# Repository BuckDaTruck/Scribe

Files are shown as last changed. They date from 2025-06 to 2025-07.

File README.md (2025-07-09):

# Scribe Audio Logger

Scribe transforms a Raspberry Pi Zero 2 W into a compact field recorder. Audio is captured continuously and each press of a hardware button marks highlights. Files can be queued for upload to a web server so recordings remain safe even if the Pi is lost.

This repository is organised into two main parts:

- **Device/** – firmware, wiring guides and setup instructions for the Raspberry Pi.
- **WebServer/** – a minimal PHP endpoint and helper scripts to receive uploads.

---

## Features

- Continuous audio capture split into timestamped chunks
- Highlight logging via a physical button
- Manual or automated upload of recordings to a server
- RGB LED status feedback and simple push‑button controls
- Old files are pruned after a successful upload to free space

---

## Hardware Overview

The hardware build uses the following components:

- Raspberry Pi Zero 2 W
- INMP441 I²S microphone
- Two push buttons: one for highlights and one for initiating uploads
- RGB LED with resistors for visual feedback

Wiring diagrams are provided in
[Device/wiring_instructions.md](Device/wiring_instructions.md).
See [Device/parts_list.md](Device/parts_list.md) for a complete list of
required components.

## 3D-Printed Case

All enclosure files live in the `Device/Cad/` directory. The STL models were
printed on an **Anycubic S1** and should be compatible with most desktop
printers. If you want to modify the design, the original Onshape project
is available at [this link](https://cad.onshape.com/documents/3eb0c03f667fd218b6465f3e/w/64f544e1ef4dcc4bc9220305/e/b0f011cba6411f833e96eb2d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).
A preconfigured `Scribe.3mf` file is also included for quick slicing.

---

## Quick Start

1. Assemble the hardware as described in the wiring instructions.
2. Follow the steps in
   [Device/Firmware/setup_instructions.md](Device/Firmware/setup_instructions.md)
   to flash the operating system and install dependencies.
3. Boot the Pi—recording starts automatically.
4. Press the highlight button to log an interesting moment.
5. Press the upload button or wait for automatic uploads to send files to the
   server configured in `recorder.py`.

Recordings are stored as `.opus` files and highlight timestamps are saved to
CSV. Successful uploads remove the local copies to keep the SD card clean.

---

## Web Server

The `WebServer` directory contains `upload.php`, a small PHP script that accepts
incoming audio and CSV files. Set `$apiKey` and `$uploadBaseDir` inside the
script to match your environment. A Python utility, `test.py`, demonstrates how
to POST files to the server for testing without the device.

---

## Repository Layout

```
Device/Cad/     # 3D models and CAD files for the case
Device/         # Firmware, setup scripts and hardware docs
WebServer/      # PHP endpoint and test client
README.md       # Project overview (this file)
```

---

## Contributing

Bug reports and pull requests are welcome. Feel free to open an issue if you run
into problems while building your own logger.

---

## License

This project is released under the MIT license. See individual source files for
full license text.

---

## Credits

Created and maintained by Buckley Wiley.

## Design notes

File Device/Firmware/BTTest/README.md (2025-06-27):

# Bluetooth Pairing Utility

This folder contains a small script to pair your Raspberry Pi with a mobile phone and use the phone's internet connection via Bluetooth PAN. A single button triggers pairing or connecting depending on whether a paired device is already saved.

## Prerequisites

Install the required packages once:

```bash
sudo apt update
sudo apt install -y bluetooth bluez pi-bluetooth rfkill python3-gpiozero python3-requests
```

(Optional) Change the advertised Bluetooth name by editing `/etc/bluetooth/main.conf` and setting:

```ini
Name = Buckley-Scribe
```

Restart Bluetooth to apply the change:

```bash
sudo systemctl restart bluetooth
```

## Usage

1. Run the helper script to clone the repository and start the pairing utility:

```bash
bash start_BT.sh
```

   This installs dependencies, pulls the repository and launches `btpair.py`.
2. Once running, press the connected button to initiate pairing. If the Pi already knows a device, it attempts to reconnect via PAN instead.
3. The script gives feedback through the RGB LED:
   - **Yellow** – pairing mode active
   - **Blue pulse** – waiting for user action
   - **Green** – internet connection detected
   - **Red** – connection failed

The MAC address of the paired phone is stored at `/etc/scribe/phone_mac.conf` for future connections.

## Files

- `btpair.py` – main script handling pairing, connection and LED feedback
- `start_BT.sh` – helper script that clones this repository and runs `btpair.py`
- `instructions.md` – brief setup notes

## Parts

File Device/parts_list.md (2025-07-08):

# Raspberry Pi Audio Logger Parts List

This list covers all hardware needed to assemble the logger.

## Electronics

- **Raspberry Pi Zero 2 W**  
  https://www.amazon.com/Pi-Zero-WH-Quad-Core-Bluetooth/dp/B0DKKXS4RV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
- **INMP441 Microphone (I2S)**  
  https://www.amazon.com/dp/B09G4RNT3G?ref_=ppx_hzsearch_conn_dt_b_fed_asin_title_3
- **RGB LED (Common Cathode)**  
  https://www.amazon.com/Tricolor-Multicolor-Lighting-Electronics-Components/dp/B01C19ENDM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
- **2x Push Buttons**  
  https://www.amazon.com/TWTADE-Yellow-Orange-6x6x5mm-Tactile/dp/B07C7211PJ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
- **3x 330Ω Resistors** (RGB LED)
- **2x 10kΩ Resistors** (buttons)
  https://www.amazon.com/TMH-525-Metal-Film-Resistor/dp/B0FD3LP495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
- **Perma-Proto Board**  
  https://www.amazon.com/dp/B0B2RQDJ54?ref=ppx_yo2ov_dt_b_fed_asin_title
- **M2.5 Standoffs**  
  https://www.amazon.com/dp/B0756CW6Y2?ref=ppx_yo2ov_dt_b_fed_asin_title
- **5V Buck Converter**  
  https://www.amazon.com/dp/B07L76KLRY?ref=ppx_yo2ov_dt_b_fed_asin_title
- **1100mAh Battery**  
  https://www.amazon.com/Hiteuoms-Rechargeable-Development-Protection-Insulated/dp/B0F3875HJY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
- **USB-C Lithium Battery Charger**  
  https://www.amazon.com/Lithium-Battery-Charging-Protection-Functions/dp/B07MDPLQ18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

## 3D Printed Parts

The `Device/Cad` directory contains STL models for printing:

- **Scribe - Back Shell.stl**
- **Scribe - TopFrame.stl**
- **2x Scribe - Button Extender.stl** (one for each button)
- **Lanyard or strap** for carrying the recorder

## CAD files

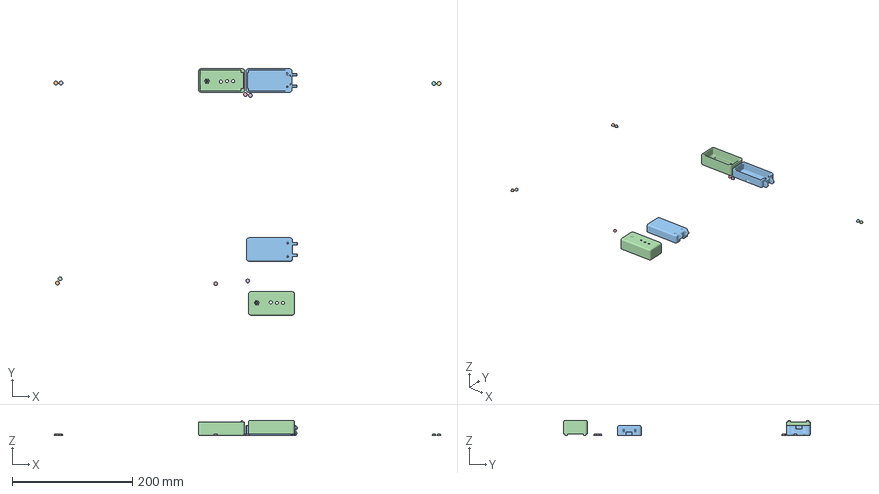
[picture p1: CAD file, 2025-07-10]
Device/Cad/Scribe.3mf
643.0 x 409.7 x 25.7 mm
Scribe - Button Extender.stl x 10
Scribe - Back Shell.stl x 2
Scribe - TopFrame.stl x 2

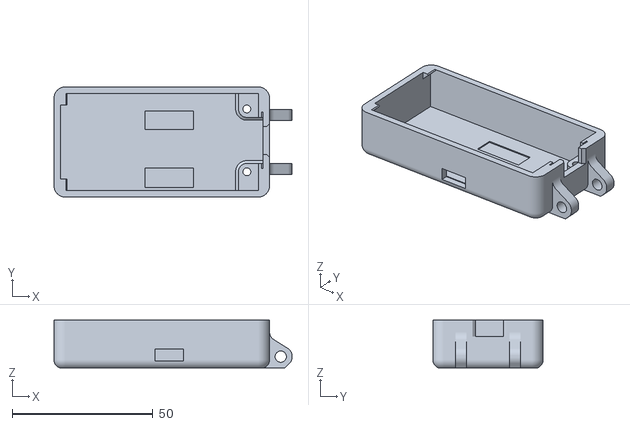
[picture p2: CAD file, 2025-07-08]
Device/Cad/Scribe - Back Shell.stl
84.7 x 39.2 x 17.0

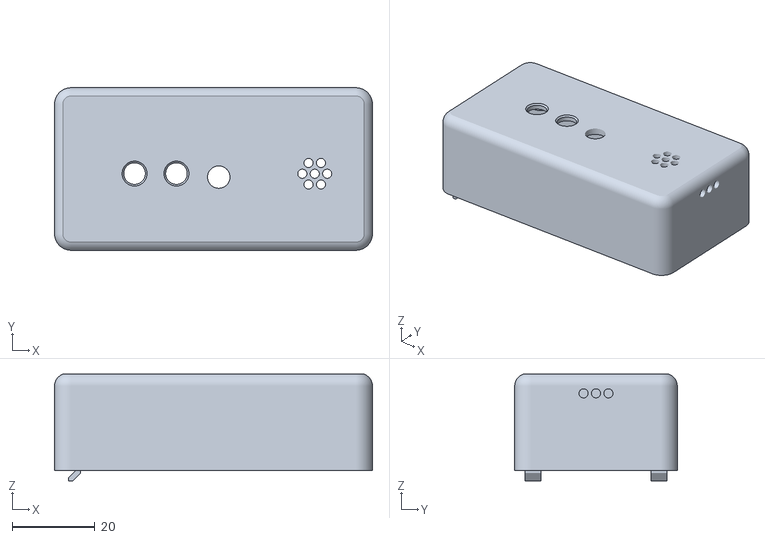
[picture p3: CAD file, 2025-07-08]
Device/Cad/Scribe - TopFrame.stl
76.7 x 39.2 x 25.7

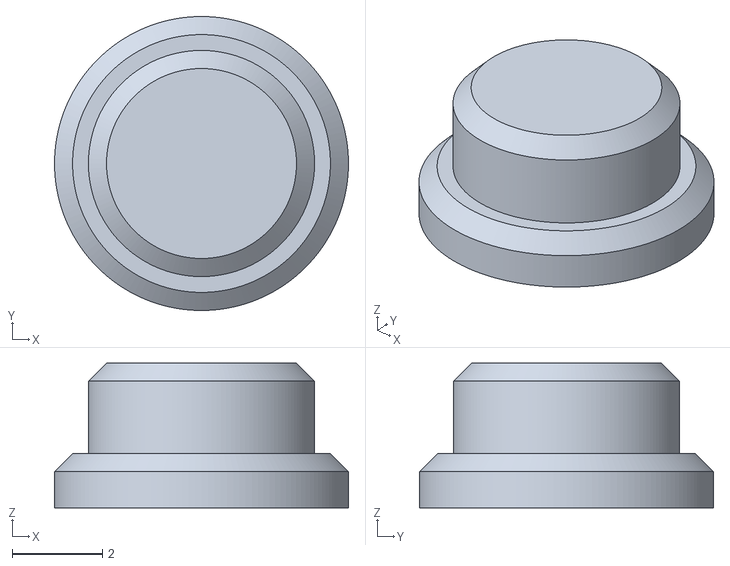
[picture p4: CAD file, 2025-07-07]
Device/Cad/Scribe - Button Extender.stl
6.50 x 6.50 x 3.20

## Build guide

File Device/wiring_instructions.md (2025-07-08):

# Raspberry Pi Audio Logger Wiring Instructions

This guide explains how to connect the electronics on the breadboard. A full list of parts is available in [parts_list.md](parts_list.md).

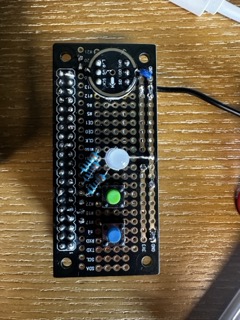
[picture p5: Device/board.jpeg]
Breadboard layout


## Wiring Diagram

### INMP441 Microphone (I2S)

| INMP441 Pin | Raspberry Pi Pin | Function |
| --- | --- | --- |
| VCC | Pin 1 (3.3V) | Power |
| GND | Pin 6 (GND) | Ground |
| WS (L/R) | Pin 35 (GPIO19)  | Word Select |
| SCK | Pin 12 (GPIO18)  | Bit Clock |
| SD | Pin 38 (GPIO20)  | Data |

> Note: You may need to enable I2S in `/boot/config.txt`:
>
> ```
> dtparam=i2s=on
> ```

---

### RGB LED (Common Cathode)

| LED Pin | Resistor | Raspberry Pi Pin | GPIO | Color  |
| --- | --- | --- | --- | --- |
| R | 330Ω | Pin 18 | GPIO24 | Red |
| G | 330Ω | Pin 16 | GPIO23 | Green  |
| B | 330Ω | Pin 15 | GPIO22 | Blue |
| Cathode | None | Pin 14 (GND) | GND | Ground |

---

### Buttons

| Button | Raspberry Pi Pin | GPIO | Function |
| --- | --- | --- | --- |
| 1 | Pin 11 | GPIO17 | Upload trigger |
| 2 | Pin 13 | GPIO27 | Highlight trigger |

Use internal pull-up resistors; buttons should connect GPIO to **GND** when pressed.

---

## Power

- You can power the Pi using a 5V lithium battery (e.g., 18650 with regulator) connected to:
  - **Pin 2 or 4** (5V)
  - **Pin 6** (GND)

Alternatively, power via USB as usual.

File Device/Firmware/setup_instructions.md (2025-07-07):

# Raspberry Pi Audio Logger Setup Instructions

## Step 1: Download Minimal OS

Download Raspberry Pi OS Lite (64-bit) from the [official Raspberry Pi website](https://www.raspberrypi.com/software/operating-systems/#raspberry-pi-os-64-bit) and flash it to a micro‑SD card using Raspberry Pi Imager or a similar tool.

---

## Step 2: Configure Boot Settings

After flashing the card, mount the **boot** partition and add the following files so that the Pi connects to your network and allows SSH on first boot:

### Enable SSH

Create an empty file named `ssh`:

```bash
touch ssh
```

### Wi‑Fi Configuration

Create a file named `wpa_supplicant.conf` with your network details:

```bash
country=US
ctrl_interface=DIR=/var/run/wpa_supplicant GROUP=netdev
network={
    ssid="YourWiFi"
    psk="YourPassword"
    key_mgmt=WPA-PSK
}
```

---

## Step 3: Install Scribe Firmware

1. Boot the Pi and log in via SSH.
2. Clone this repository:

```bash
git clone https://github.com/BuckDaTruck/Scribe.git
```

3. Move the startup script to your home directory (the main directory) so it can be used at boot:

```bash
cd Scribe/Device/Firmware
mv start_scribe.sh ~/start_scribe.sh
chmod +x ~/start_scribe.sh
```

4. Run the helper script to install dependencies and start the recorder:

```bash
bash ~/start_scribe.sh
```

`start_scribe.sh` installs required packages, uses `requirements.txt` to install Python dependencies, and launches `recorder.py`.

If you prefer a manual setup, run the following instead of the script:

```bash
sudo apt-get update
sudo apt-get install -y python3 python3-pip alsa-utils git
pip3 install -r requirements.txt
python3 recorder.py
```

---

## Step 4: Optional – Run on Boot

After moving `start_scribe.sh` to your home directory, you can configure
systemd to run it automatically on boot:

```bash
sudo nano /etc/systemd/system/scribe.service
```

Insert:

```ini
[Unit]
Description=Scribe Recorder
After=network.target

[Service]
ExecStart=/bin/bash /home/pi/start_scribe.sh
Restart=always
User=pi

[Install]
WantedBy=multi-user.target
```

Enable and start the service:

```bash
sudo systemctl daemon-reload
sudo systemctl enable scribe.service
sudo systemctl start scribe.service
```

To stop the service and disable it from starting at boot:

```bash
sudo systemctl stop scribe.service
sudo systemctl disable scribe.service
```

---

## Step 5: Record

After running `start_scribe.sh` or enabling the service, the Pi begins recording immediately. Use the connected buttons to mark highlights and to upload recordings as defined in `recorder.py`.

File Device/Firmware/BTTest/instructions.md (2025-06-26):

✅ STEP 1: Install Required Packages
Run this once:

bash
Copy
Edit
sudo apt update
sudo apt install -y bluetooth bluez pi-bluetooth rfkill python3-gpiozero python3-requests
✅ STEP 2: Change the Bluetooth Name Only
Edit the Bluetooth config:

bash
Copy
Edit
sudo nano /etc/bluetooth/main.conf
Find (or add) the following line under [General]:

ini
Copy
Edit
Name = Buckley-Scribe
Then restart Bluetooth:

bash
Copy
Edit
sudo systemctl restart bluetooth
✅ Your Pi will now appear as Buckley-Scribe when other devices scan via Bluetooth.

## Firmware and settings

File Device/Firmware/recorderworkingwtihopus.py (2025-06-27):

import os
import time
import uuid
import threading
import subprocess
import datetime
import glob
import requests
import math
import logging
from gpiozero import Button, PWMLED
#:~ $ ./start_scribe.sh 
# === CONFIG ===
DEVICE_ID = "Buckley-Scribe-v1.1"
SCRIPT_DIR = os.path.dirname(os.path.realpath(__file__))
AUDIO_DIR = SCRIPT_DIR
os.makedirs(AUDIO_DIR, exist_ok=True)

UPLOAD_URL = 'https://buckleywiley.com/Scribe/upload.php'
API_KEY = '@YourPassword123'
BUTTON_HIGHLIGHT = Button(27, bounce_time=0.1)
BUTTON_UPLOAD = Button(17, bounce_time=0.1)
CHUNK_DURATION = .5 * 60  # 30 minutes
MAX_UPLOADED = 5
last_upload_time = 0
UPLOAD_DEBOUNCE_SEC = 2.0  # Prevent triggering more than once every 2 seconds

# === LOGGING SETUP ===
LOG_PATH = os.path.join(SCRIPT_DIR, 'scribe.log')
logging.basicConfig(
    filename=LOG_PATH,
    filemode='a',
    format='[%(asctime)s] %(levelname)s: %(message)s',
    datefmt='%Y-%m-%d %H:%M:%S',
    level=logging.INFO
)

def log(message, level='info'):
    print(message)
    getattr(logging, level)(message)

# === LED SETUP ===
led_r = PWMLED(24)
led_g = PWMLED(23)
led_b = PWMLED(22)

def set_led(r=0, g=0, b=0):
    led_r.value = r
    led_g.value = g
    led_b.value = b

def pulse_led(r=0, g=0, b=0, duration=10, delay=0.05):
    stop_event = threading.Event()
    def pulser():
        start = time.time()
        while time.time() - start < duration and not stop_event.is_set():
            t = time.time() * 2
            brightness = (math.sin(t) + 1) / 2
            led_r.value = brightness * r
            led_g.value = brightness * g
            led_b.value = brightness * b
            time.sleep(delay)
        if not stop_event.is_set():
            set_led(0, 0, 0)
    thread = threading.Thread(target=pulser, daemon=True)
    thread.start()
    return stop_event

# === TRIPLE TAP DETECTION ===
last_tap_time = 0
tap_count = 0
idle_mode = False
pulse_thread = None
pulse_event = threading.Event()

def idle_led_pulse():
    while not pulse_event.is_set():
        for i in range(100):
            if pulse_event.is_set(): return
            val = (math.sin(time.time() * 2) + 1) / 2
            led_g.value = val
            led_b.value = 1 - val
            time.sleep(0.05)
        set_led(0, 0, 0)


def quick_flash(r=0, g=0, b=0, duration=0.2):
    set_led(r, g, b)
    time.sleep(duration)
    set_led(0, 0, 0)

def set_error_led():
    set_led(r=1, g=0, b=0)

def startup_sequence():
    log("[SYSTEM] Running startup LED sequence...")
    colors = [
        (1, 0, 0),   # Red
        (1, 0.5, 0), # Orange
        (1, 1, 0),   # Yellow
        (0, 1, 0),   # Green
        (0, 0, 1),   # Blue
        (0.29, 0, 0.51), # Indigo
        (0.56, 0, 1),    # Violet
    ]
    for r, g, b in colors:
        set_led(r, g, b)
        time.sleep(0.2)
    set_led(0, 0, 0)
    time.sleep(0.3)
    set_led(1, 1, 1)
    time.sleep(0.2)
    set_led(0, 0, 0)
    log("[SYSTEM] LED sequence complete.")

# === STATE ===
current_arecord_proc = None
current_lame_proc = None
highlight_lock = threading.Lock()
highlighting = []
highlight_led_stop = None
session_id = uuid.uuid4().hex[:8]
session_part = 1

# === AUDIO RECORDING ===
def start_new_recording():
    global current_arecord_proc, current_lame_proc, session_part, current_csv_path
    timestamp = datetime.datetime.now().strftime('%Y-%m-%d_%H-%M-%S')
    print(f"Session ID {session_id}")
    filename = f"part_{session_part:04}.opus"
    filepath = os.path.join(AUDIO_DIR, filename)
    current_csv_path = os.path.join(AUDIO_DIR, f"{session_id}_Highlights.csv")
    session_part += 1

    log(f"[INFO] Starting opus recording: {filename}")
    current_arecord_proc = subprocess.Popen([
        'arecord', '-D', 'plughw:1,0', '-f', 'S16_LE', '-r', '88200', '-c', '1',
        '-t', 'raw', '-q', '-',
    ], stdout=subprocess.PIPE)

    sox_proc = subprocess.Popen([
    'sox', '-t', 'raw', '-r', '16000', '-e', 'signed', '-b', '16', '-c', '1', '-',  # raw PCM input
    '-t', 'raw', '-', 'gain', '10'  # actual amplification
    ], stdin=current_arecord_proc.stdout, stdout=subprocess.PIPE)

    current_lame_proc = subprocess.Popen([
    'opusenc', '--raw', '--raw-rate', '88200', '--raw-chan', '1', '-', filepath
    ], stdin=sox_proc.stdout, stdout=subprocess.DEVNULL, stderr=subprocess.DEVNULL)

    sox_proc.stdout.close()
    current_arecord_proc.stdout.close()
    set_led(r=0, g=1, b=0)
    return filepath
#opus works Finally
# === HIGHLIGHT BUTTON ===
def on_highlight_pressed():
    global highlight_led_stop, current_csv_path
    press_time = datetime.datetime.now()
    start_time = press_time - datetime.timedelta(seconds=10)
    end_time = press_time + datetime.timedelta(seconds=10)

    log(f"[HIGHLIGHT] Start: {start_time}, End: {end_time}")
    with highlight_lock:
        highlighting.append((start_time, press_time, end_time))

    if current_csv_path:
        with open(current_csv_path, 'a') as f:
            f.write(f"{start_time},{press_time},{end_time}\n")

    if highlight_led_stop:
        highlight_led_stop.set()
        set_led(r=0, g=1, b=0)

    highlight_led_stop = pulse_led(r=0, g=1, b=0, duration=5 * 60)

# === UPLOAD BUTTON ===
def on_upload_pressed():
    global idle_mode, pulse_event, last_upload_time, session_id, session_part
    now = time.time()

    # Manual debounce protection
    if now - last_upload_time < UPLOAD_DEBOUNCE_SEC:
        log("[UPLOAD] Ignored: Debounced repeated press.")
        return
    last_upload_time = now

    if not idle_mode:
        log("[UPLOAD] Upload button pressed. Stopping and entering idle mode.")
        if current_arecord_proc:
            current_arecord_proc.terminate()
            current_arecord_proc.wait()
        if current_lame_proc:
            current_lame_proc.terminate()
            current_lame_proc.wait()
        prev_filename = f"part_{session_part - 1:04}.opus"
        upload(prev_filename)
        idle_mode = True
        pulse_event.clear()
        pulse_event = threading.Event()
        threading.Thread(target=idle_led_pulse, daemon=True).start()
    else:
        log("[UPLOAD] Upload button pressed. Starting new recording session.")
        pulse_event.set()  # stop pulsing
        set_led(0, 0, 0)
        idle_mode = False
        session_id = uuid.uuid4().hex[:8]
        session_part = 1
        start_new_recording()


BUTTON_HIGHLIGHT.when_pressed = on_highlight_pressed
BUTTON_UPLOAD.when_pressed = on_upload_pressed

# === FILE UPLOAD ===
def upload(target_opus_filename):
    global highlight_led_stop
    opus_path = os.path.join(AUDIO_DIR, target_opus_filename)

    if not os.path.isfile(opus_path):
        log(f"[UPLOAD] File not found: {opus_path}", level='error')
        return

    # Find the CSV file (current session)
    csv_files = glob.glob(os.path.join(AUDIO_DIR, "*.csv"))
    csv_path = csv_files[0] if csv_files else None

    multipart = {
        'api_key': API_KEY,
        'device_id': DEVICE_ID,
        'session_id': session_id
    }

    files = {}
    try:
        files[target_opus_filename] = open(opus_path, 'rb')
        if csv_path:
            files[os.path.basename(csv_path)] = open(csv_path, 'rb')

        log(f"[UPLOAD] Uploading: {list(files.keys())}")
        pulse = pulse_led(r=0, g=0, b=1, duration=999)

        response = requests.post(UPLOAD_URL, files=files, data=multipart)
        log(f"[UPLOAD] Response: {response.status_code} - {response.text}")

        if pulse:
            pulse.set()
        set_led(0, 0, 0)

        if response.status_code == 200:
            try:
                os.remove(opus_path)
                log(f"[UPLOAD] Deleted: {opus_path}")
            except Exception as e:
                log(f"[UPLOAD] Delete failed for {opus_path}: {e}", level='error')
            if csv_path:
                try:
                    os.remove(csv_path)
                    log(f"[UPLOAD] Deleted: {csv_path}")
                except Exception as e:
                    log(f"[UPLOAD] Delete failed for {csv_path}: {e}", level='error')
            quick_flash(b=1)
        else:
            log("[UPLOAD] Upload failed.", level='error')
            quick_flash(r=1)

    except Exception as e:
        log(f"[UPLOAD] Exception: {e}", level='error')
        quick_flash(r=1)
        set_error_led()
    finally:
        for f in files.values():
            f.close()


# === AUTO-UPLOAD THREAD ===
def auto_uploader():
    while True:
        time.sleep(CHUNK_DURATION)
        #upload_files()

    

# === MAIN LOOP ===
def main():
    global current_arecord_proc, current_lame_proc
    global idle_mode

    print("[SYSTEM] Starting Scribe Recorder...")
    log(f"[SYSTEM] Recorder started. Device ID: {DEVICE_ID}")
    print(f"[SYSTEM] Device ID: {DEVICE_ID}")
    print(f"[SYSTEM] Audio Directory: {AUDIO_DIR}")
    print("[SYSTEM] Log file: " + LOG_PATH)
    print("Welcome to the Scribe Audio Recorder!")
    print("Audio recording will start automatically.")
    print("Audio is sent to BuckleyWiley.com for processing.")
    print("Press the highlight button to mark highlights.")
    print("Press the upload button to stop/start recording and upload.")
    print("The LEDS will indicate status.")
    print("Green: Recording")
    print("Pulsing Green: Highlighting")
    print("Pulsing Blue: Uploading")
    print("Pulsing Green/Blue: Idle mode")
    print("Red: Error")
    print("White flash: Startup complete")

    startup_sequence()

    # Start first recording
    start_new_recording()

    while True:
        try:
            if idle_mode:
                time.sleep(1)
                continue

            # Record for CHUNK_DURATION
            start_time = time.time()
            while time.time() - start_time < CHUNK_DURATION:
                if idle_mode:
                    break
                time.sleep(1)
                set_led(r=0, g=1, b=0)  # Green while recording

            if idle_mode:
                continue

            # Stop current recording
            if current_arecord_proc:
                current_arecord_proc.terminate()
                current_arecord_proc.wait()
                current_arecord_proc = None
            if current_lame_proc:
                current_lame_proc.terminate()
                current_lame_proc.wait()
                current_lame_proc = None

            #remember Previous filename
            prev_filename = f"part_{session_part - 1:04}.opus"
            # Start a new recording
            start_new_recording()
            # Upload the previous file (not the one about to be created)
            upload(prev_filename)

            
            

        except Exception as e:
            log(f"[MAIN] Error: {e}", level='error')
            set_error_led()
            time.sleep(10)



if __name__ == "__main__":
    main()

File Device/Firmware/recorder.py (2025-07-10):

import os
import time
import uuid
import threading
import subprocess
import datetime
import requests
import wave
import logging
import math
from gpiozero import Button, PWMLED

# === CONFIG ===
DEVICE_ID        = "Buckley-Scribe-v1.2"#stable
SCRIPT_DIR       = os.path.dirname(os.path.realpath(__file__))
AUDIO_DIR        = SCRIPT_DIR
os.makedirs(AUDIO_DIR, exist_ok=True)

UPLOAD_URL       = 'http://172.20.10.12:3000/api/audio/upload'
API_KEY          = '@YourPassword123'
BUTTON_HIGHLIGHT = Button(27, bounce_time=0.1)
BUTTON_UPLOAD    = Button(17, bounce_time=0.1)

# audio parameters
SAMPLE_RATE      = 88200
BYTES_PER_SAMPLE = 2    # 16-bit
CHANNELS         = 1
CHUNK_SECONDS    = 1
CHUNK_SIZE       = SAMPLE_RATE * BYTES_PER_SAMPLE * CHANNELS * CHUNK_SECONDS

# ALSA tuning
ARECORD_BUFFER_SIZE = 2 * 1048576   # 2 MB
ARECORD_PERIOD_SIZE = 131072        # 128 KB

UPLOAD_DEBOUNCE_SEC = 2.0
last_upload_time    = 0
idle_mode           = False
session_id          = uuid.uuid4().hex[:8]
chunk_counter       = 0

# === LOGGING ===
LOG_PATH = os.path.join(SCRIPT_DIR, 'scribe.log')
logging.basicConfig(
    filename=LOG_PATH, filemode='a',
    format='[%(asctime)s] %(levelname)s: %(message)s',
    datefmt='%Y-%m-%d %H:%M:%S',
    level=logging.INFO
)
def log(msg, level='info'):
    print(msg)
    getattr(logging, level)(msg)

# === LEDs ===
led_r = PWMLED(24)
led_g = PWMLED(23)
led_b = PWMLED(22)

def set_led(r=0, g=0, b=0):
    led_r.value, led_g.value, led_b.value = r, g, b

# State for LED controller
recording_start_time = None
highlight_start       = None
highlight_until       = 0
crossfade_start_time  = time.time()

# === LED CONTROLLER ===
def led_controller():
    global recording_start_time, highlight_start, highlight_until, crossfade_start_time

    crossfade_period = 4.0    # seconds for full blue↔green cycle
    pulse_period     = 2.0    # pulse period for highlights and blue pulses
    refresh_rate     = 0.05   # 50 ms update

    while True:
        now = time.time()

        if idle_mode:
            # end any highlight
            highlight_until = 0
            # smooth crossfade idle between blue and green and back
            phase = ((now - crossfade_start_time) % crossfade_period) / crossfade_period
            g_val = 0.5 * (1 - math.cos(2 * math.pi * phase))
            b_val = 0.5 * (1 + math.cos(2 * math.pi * phase))
            set_led(0, g_val, b_val)
            recording_start_time = None

        else:
            # Highlight override during recording
            if highlight_start and now < highlight_until:
                phase      = ((now - highlight_start) % pulse_period) / pulse_period
                brightness = (math.sin(2 * math.pi * phase) + 1) / 2
                set_led(0, brightness, 0)

            else:
                # Recording mode without highlight or after highlight expired
                if recording_start_time is None:
                    recording_start_time = now
                    # reset fade when returning to idle later
                    crossfade_start_time = now
                elapsed = now - recording_start_time
                if elapsed < 5:
                    # blue pulse for first 5s
                    phase      = (elapsed % pulse_period) / pulse_period
                    brightness = (math.sin(2 * math.pi * phase) + 1) / 2
                    set_led(0, 0, brightness)
                else:
                    # solid green afterwards
                    set_led(0, 1, 0)

        time.sleep(refresh_rate)

# === UPLOAD WORKER ===
chunk_counter = 0

def async_upload(chunk_bytes, is_csv=False):
    global chunk_counter
    
    if is_csv:
        # Skip CSV uploads for now - focus on audio
        log("[UPLOAD] Skipping CSV upload (not implemented for new API)")
        return
    
    chunk_counter += 1
    
    # Convert bytes to list of integers for the API
    audio_data = list(chunk_bytes)
    
    payload = {
        "userId": DEVICE_ID,
        "timestamp": int(time.time() * 1000),
        "audioData": audio_data,
        "chunkId": f"{session_id}-chunk-{chunk_counter}",
        "sessionId": session_id
    }
    
    try:
        resp = requests.post(
            UPLOAD_URL, 
            json=payload,
            headers={'Content-Type': 'application/json'},
            timeout=10
        )
        if resp.status_code != 200:
            log(f"[UPLOAD][ERROR] {resp.status_code}: {resp.text}", 'error')
        else:
            response_data = resp.json()
            log(f"[UPLOAD] Success: {response_data.get('message', 'OK')}")
            print(f"Audio chunk {chunk_counter} uploaded.")
    except Exception as e:
        log(f"[UPLOAD][EXCEPTION] {e}", 'error')

# === STREAMING ===
def stream_audio():
    global idle_mode, session_id

    wav_path = os.path.join(AUDIO_DIR, f"{session_id}.wav")
    wf = wave.open(wav_path, 'wb')
    wf.setnchannels(CHANNELS)
    wf.setsampwidth(BYTES_PER_SAMPLE)
    wf.setframerate(SAMPLE_RATE)

    arec = subprocess.Popen([
        'arecord', '-D', 'plughw:1,0',
        '-f', 'S16_LE', '-r', str(SAMPLE_RATE), '-c', str(CHANNELS),
        '--buffer-size', str(ARECORD_BUFFER_SIZE),
        '--period-size', str(ARECORD_PERIOD_SIZE),
        '-t', 'raw', '-q', '-'
    ], stdout=subprocess.PIPE)

    sox = subprocess.Popen([
        'sox',
        '-t', 'raw', '-r', str(SAMPLE_RATE),
        '-e', 'signed-integer', '-b', '16', '-c', str(CHANNELS), '-',
        '-t', 'raw', '-',
        'gain', '10'
    ], stdin=arec.stdout, stdout=subprocess.PIPE)

    log("[STREAM] Starting audio…")
    try:
        while not idle_mode:
            chunk = sox.stdout.read(CHUNK_SIZE)
            if not chunk:
                break
            wf.writeframes(chunk)
            threading.Thread(target=async_upload, args=(chunk,), daemon=True).start()
    finally:
        wf.close()
        arec.terminate()
        sox.terminate()
        log("[STREAM] Stopped.")

# === HIGHLIGHT ===
def on_highlight_pressed():
    global highlight_start, highlight_until
    # record timestamps
    t0 = datetime.datetime.now() - datetime.timedelta(seconds=10)
    t1 = datetime.datetime.now()
    t2 = t1 + datetime.timedelta(seconds=10)
    entry = f"{t0},{t1},{t2}\n"
    csv_path = os.path.join(AUDIO_DIR, f"{session_id}_Highlights.csv")
    with open(csv_path, 'a') as f:
        f.write(entry)
    # immediate upload of full CSV
    try:
        with open(csv_path, 'rb') as f:
            csv_bytes = f.read()
        threading.Thread(target=async_upload, args=(csv_bytes, True), daemon=True).start()
    except Exception as e:
        log(f"[HIGHLIGHT][ERROR] CSV upload failed: {e}", 'error')
    # start highlight pulse
    highlight_start = time.time()
    highlight_until = highlight_start + 10
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

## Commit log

2025-06-26 Add internet check and improve Bluetooth pairing flow
    Introduces a check_internet function with LED feedback, improves Bluetooth pairing by scripting bluetoothctl commands, adds PAN connection logic, and ensures MAC file directory exists before saving. 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
2025-06-27 Update GPIO pin assignments for LEDs and buttons
    Swapped GPIO assignments for the highlight and upload buttons, as well as the red and blue LEDs, in both recorder.py and wiring_instructions.md to match the correct hardware wiring. This ensures the software aligns with the documented and physical pinout.
    [recorder.py]
2025-07-07 Add Scribe CAD files and 3D models
    Added STL files for the Scribe Back Shell, Button Extender, and TopFrame, as well as the Scribe.3mf project file. These files are required for 3D printing and CAD work related to the Scribe project.
    [Scribe - Back Shell.stl, Scribe - Button Extender.stl, Scribe - TopFrame.stl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]
2025-07-07 Update audio streaming to use raw PCM and clarify UI
    Changed audio streaming to send raw PCM data instead of WAV, updating MIME type and file extension accordingly. Improved startup messages and button/LED instructions for clarity, and updated comments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
2025-07-07 Refactor audio streaming and highlight upload logic
    Streamlined audio streaming to use 1-second chunks, improved arecord/sox buffer sizes, and switched to background thread uploads for both audio and highlight CSVs. Simplified highlight and upload but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
2025-07-07 Enhance LED control and support RAW audio upload
    Refactored recorder.py to implement a background LED controller with smooth transitions for idle, recording, and highlight states. Updated upload2.php to accept and process both WAV and RAW audio chu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
2025-07-07 Refactor LED controller logic and cleanup recorder.py
    Simplifies and clarifies the LED controller logic for idle, recording, and highlight states. Removes redundant comments and variables, improves highlight and crossfade timing, and streamlines button 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
2025-07-07 Refactor LED and highlight logic in recorder.py
    Improves LED control logic for idle and recording modes, ensuring highlight pulses only occur during recording and resetting highlight state when entering idle. Refactors highlight CSV upload to be immediate and synchronous, and simplifies upload button behavior to avoid triggering highlight on upload.
    [recorder.py]
2025-07-07 Improve LED effects and highlight upload handling
    Refines LED crossfade logic for smoother blue-green transitions and clarifies comments. Updates highlight button behavior to upload the entire CSV file asynchronously and adds error handling for upload failures. Also reorganizes main setup for clarity and ensures main thread stays alive.
    [recorder.py]
2025-07-07 Refactor upload endpoints and update recorder configs
    Moved legacy recorder script and upload handler to 'Archived Files'. Updated recorder.py and recorderworkingwtihopus.py to use the correct upload URLs. Replaced upload2.php with upload.php as the main upload endpoint, consolidating audio chunk streaming and file upload logic. Added user instructions and improved logging in recorder.py.
    [recorder.py, recorderworkingwtihopus.py]
2025-07-07 Add CAD printing details to README
2025-07-07 Add board.jpeg image to Device directory
    Added a new image file, board.jpeg, to the Device directory. Updated .DS_Store files due to changes in directory contents.
2025-07-07 Move CAD files to Device directory and update docs
    Relocated STL and 3MF CAD files from the Cad directory to Device/Cad for better organization. Updated wiring_instructions.md to add Amazon links for all listed components and included additional link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
    [Scribe - Back Shell.stl, Scribe - Button Extender.stl, Scribe - TopFrame.stl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]
2025-07-07 Update Scribe Button Extender STL file
    Modified the 'Scribe - Button Extender.stl' file in Device/Cad. Also added and updated .DS_Store files, likely due to changes in the directory structure or local environment.
    [Scribe - Button Extender.stl]
2025-07-08 Split parts list and update wiring guide
2025-07-08 Update CAD directory path
2025-07-08 Update Scribe CAD files
    Updated the Scribe.3mf, Back Shell.stl, and TopFrame.stl files in the Device/Cad directory with new versions. These changes likely reflect design modifications or improvements to the Scribe device's 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
    [Scribe - Back Shell.stl, Scribe - TopFrame.stl, Scribe.3mf]
2025-07-08 Update Scribe Back Shell and TopFrame STL files
    Revised the 3D models for the Scribe device's Back Shell and TopFrame. These updates may include design improvements or corrections to the CAD files.
    [Scribe - Back Shell.stl, Scribe - TopFrame.stl]
2025-07-08 Update Scribe.3mf CAD model
    Modified the Scribe.3mf file in the Device/Cad directory.
    [Scribe.3mf]
2025-07-10 Add audio manager with transcription and folder rename
    Introduces audio_manager.php for managing audio folders, renaming folders, and transcribing audio files using AssemblyAI. Adds a .gitignore for local environment files and updates the Scribe.3mf CAD 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
    [Scribe.3mf]
2025-07-10 Update audio upload to new API and add chunk counter
    Changed the audio upload endpoint in recorder.py to a new API URL and updated the upload logic to send audio data as a JSON payload with chunk IDs. Introduced a chunk_counter to track and label audio chunks per session. Added logic to reset the chunk counter on new sessions and improved upload logging. Added recordersendtobwweb.py as a backup or legacy version using the old upload endpoint.
    [recordersendtobwweb.py]
